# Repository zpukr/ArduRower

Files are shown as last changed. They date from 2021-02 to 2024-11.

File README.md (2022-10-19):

# ArduRower
The project was created on the basis of the ESP32 board (Heltec WiFi Kit 32 - cheap ESP32 board with OLED & LiPo battery interface) for equipping chinese clones of waterrower like Incline, XtremepowerUS, Hunter, Fit-On or DIY rowing machines with a 0.96-inch OLED screen and bluetooth interface. The device have emulates the work of the original WaterRower S4 equipped with a bluetooth comm module. Tested work with the **Coxswain** app, which allows to record and export your workouts to Garmin Connect and/or Strava, work with **Kinomap**, **HOLOFIT** and probably other applications that support the **FiTness Machine Service** protocol better known as **FTMS**. To connect to your rowing machine, you only need to attach two GND and GPIO2 wires to the RPM sensor (you can add 1kΩ resistor or similar on each wire for protection ESP32 board). You can also connect the battery to GPIO33 through a divider of two resistors: 220kΩ resistance connects to "+" of LiPo battery and GPIO33, 100kΩ resistance to GND and GPIO33

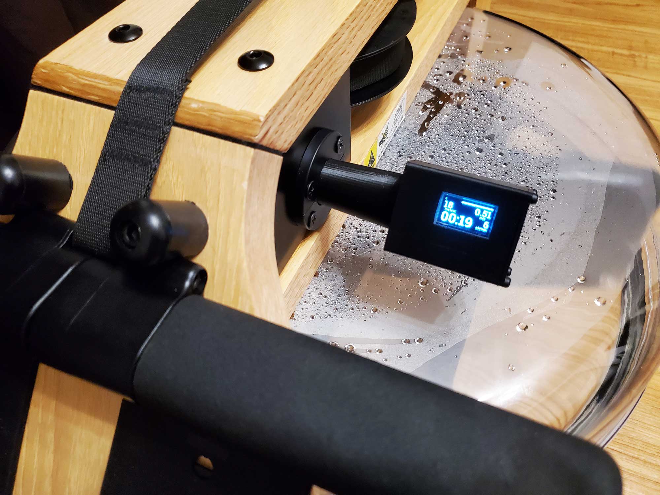
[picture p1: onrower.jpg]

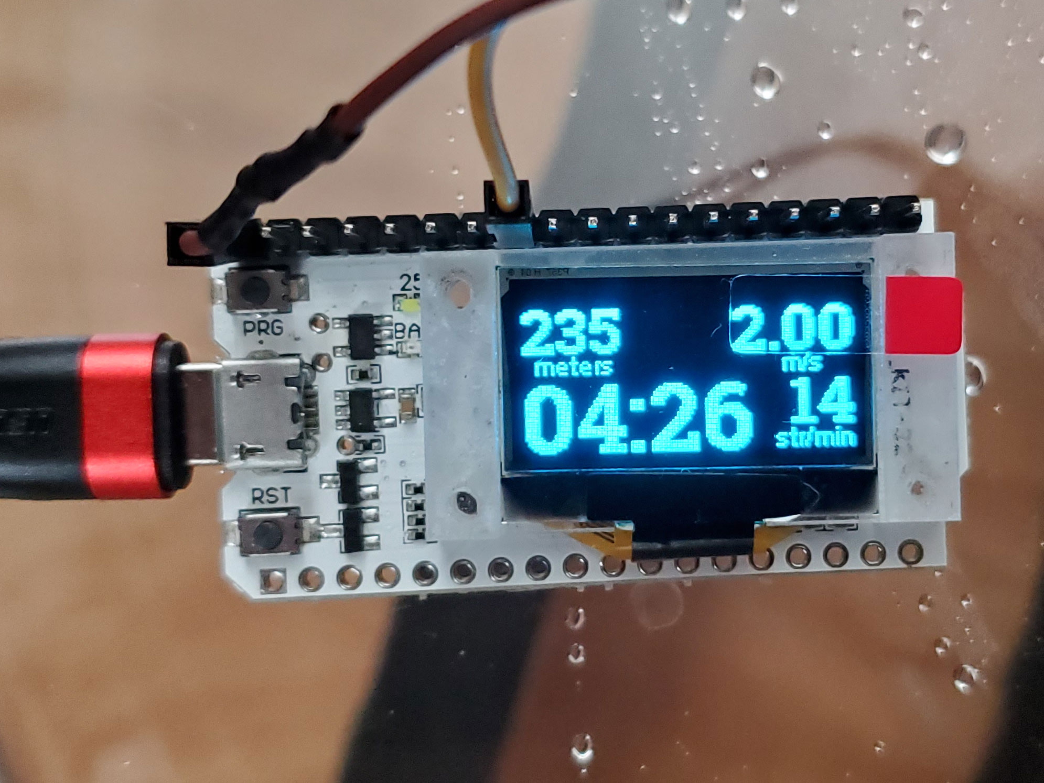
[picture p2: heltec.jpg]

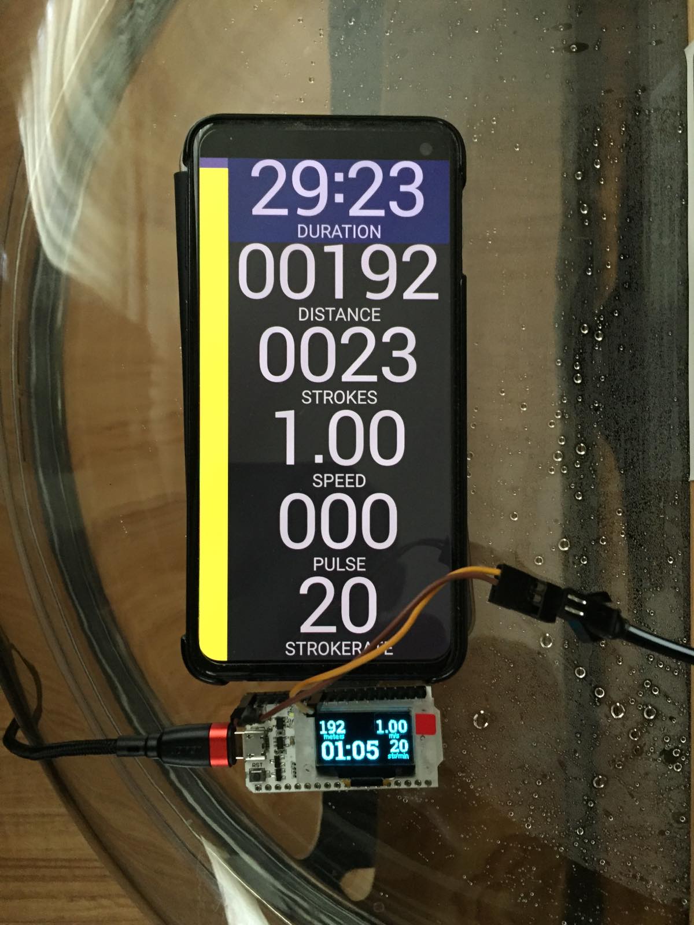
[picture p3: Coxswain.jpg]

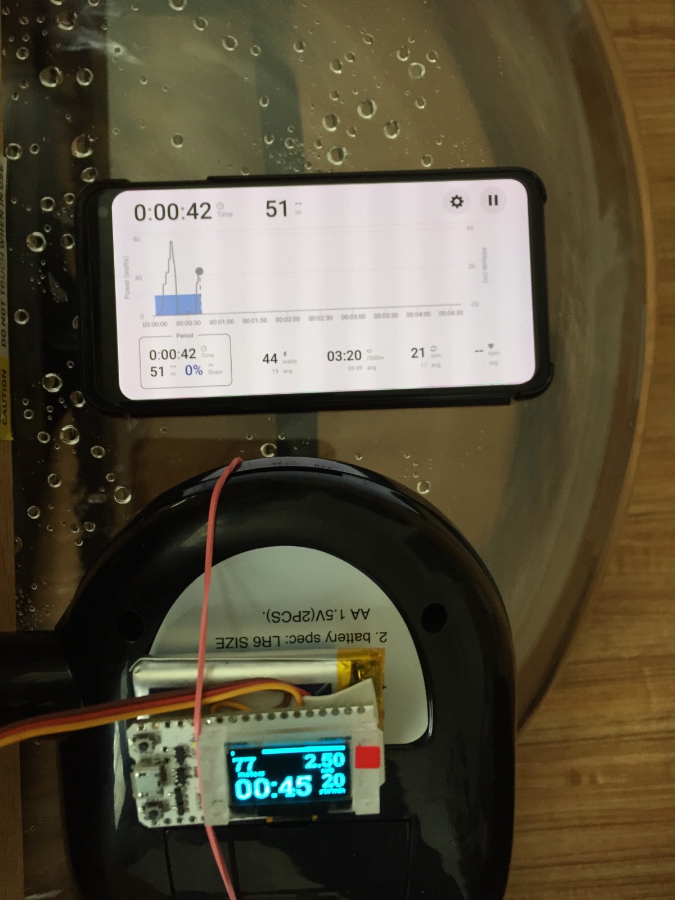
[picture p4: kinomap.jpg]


It is possible to write directly to the Garmin Connect using the Connect IQ DataField **ArduRower-IQ** https://apps.garmin.com/en-US/apps/0e10bae1-9753-4915-b856-040d0cbdd82a 

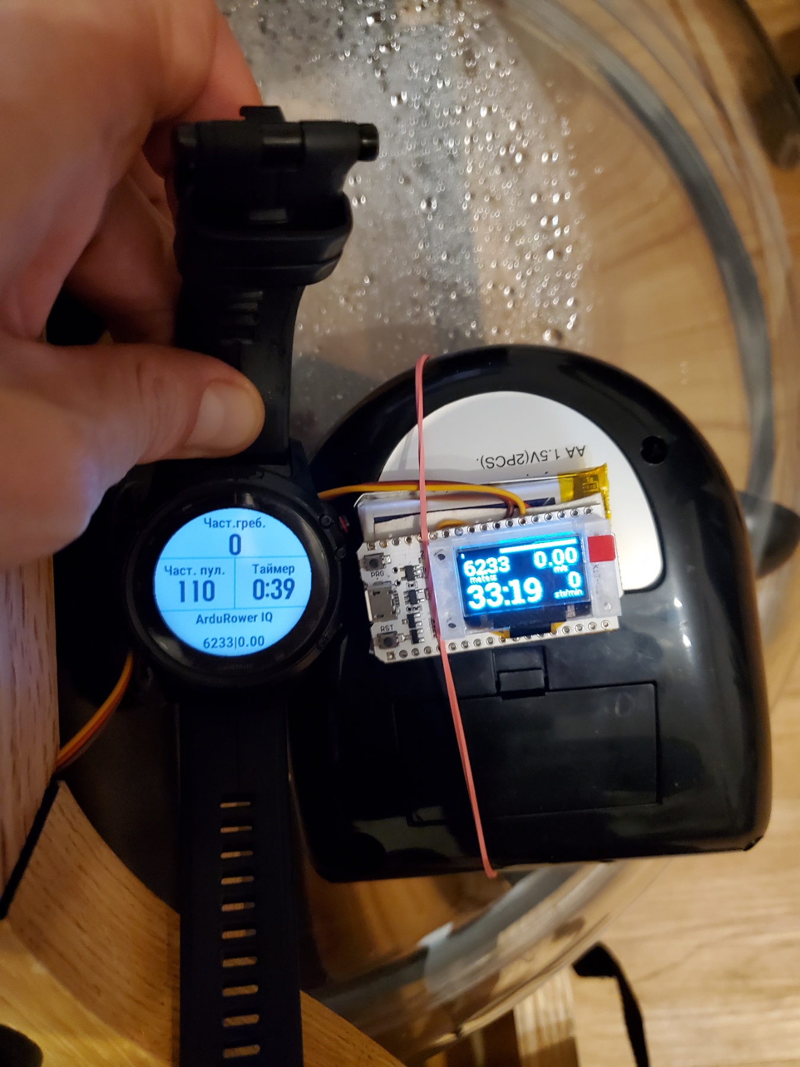
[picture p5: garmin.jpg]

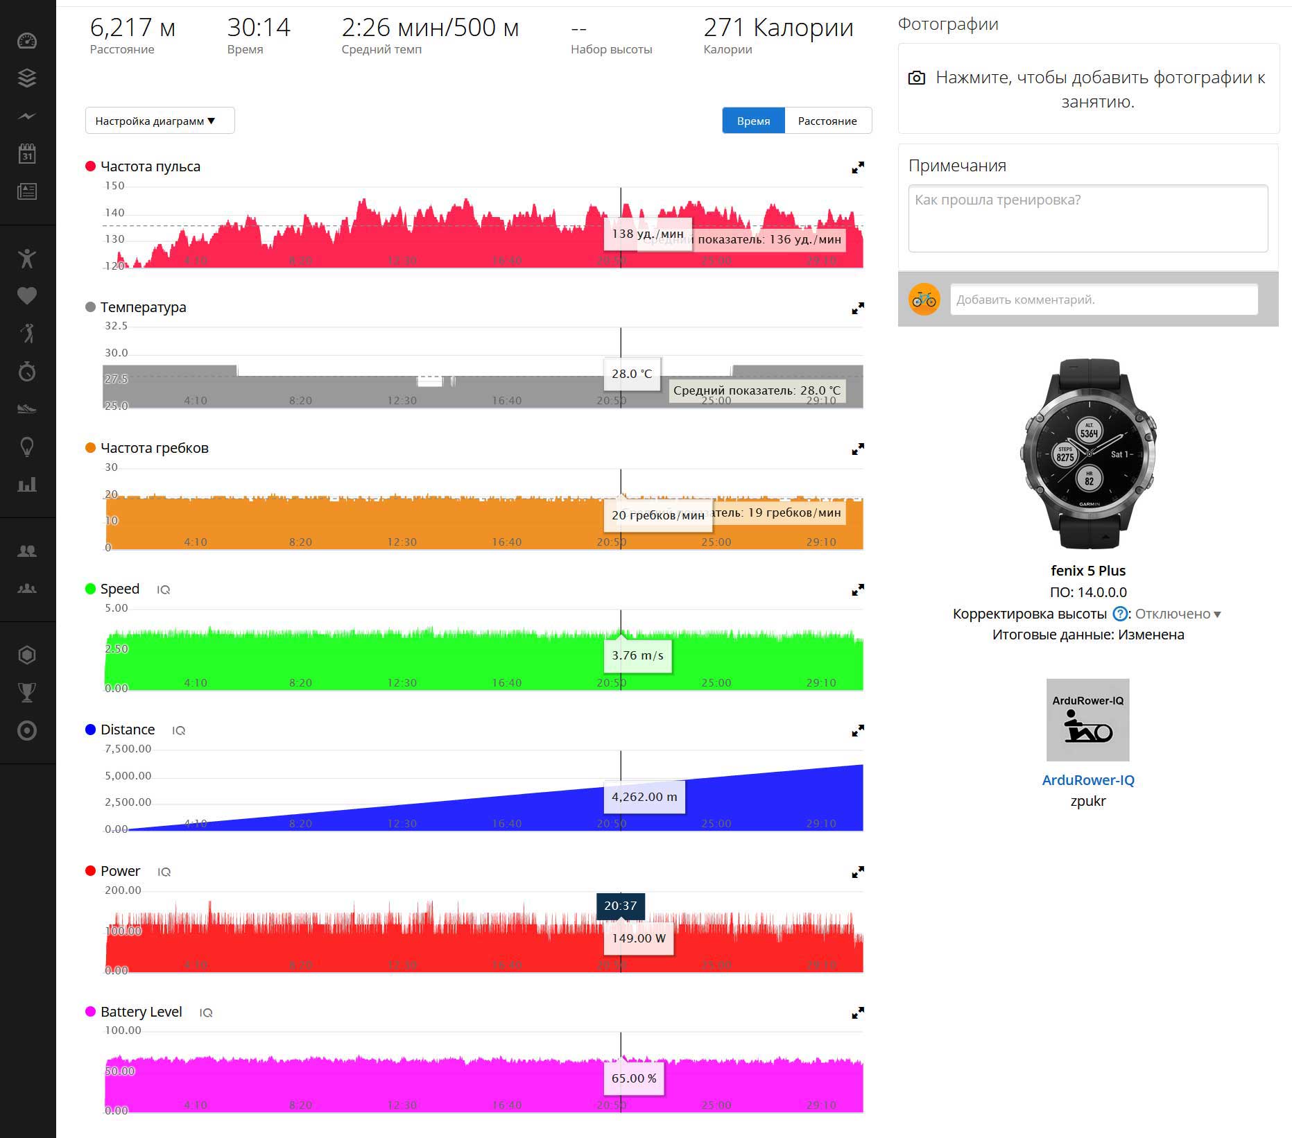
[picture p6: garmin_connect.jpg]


Rower side based on sketch **WaterRino**: https://github.com/adruino-io/waterrino                          
Bluetooth side on sketch **WaterRower S4BL3 Bluetooth BLE for S4**: https://github.com/vibr77/wr_s4bl3_samd

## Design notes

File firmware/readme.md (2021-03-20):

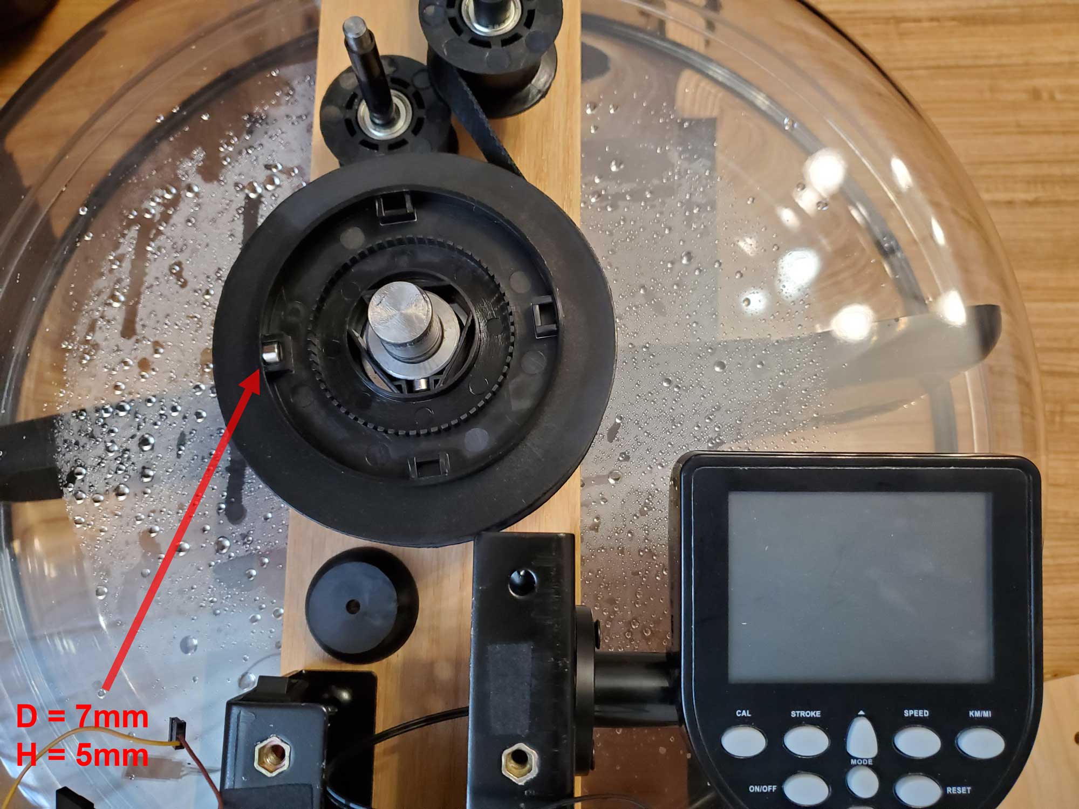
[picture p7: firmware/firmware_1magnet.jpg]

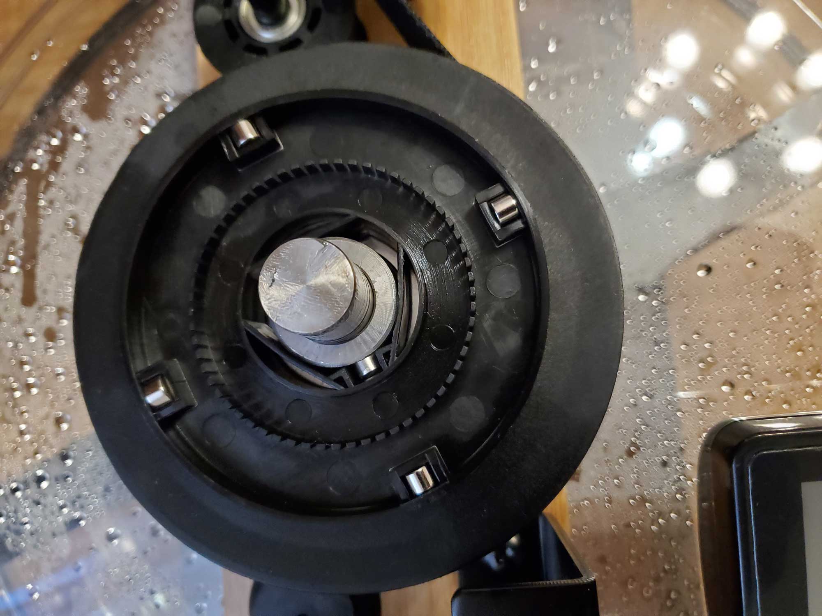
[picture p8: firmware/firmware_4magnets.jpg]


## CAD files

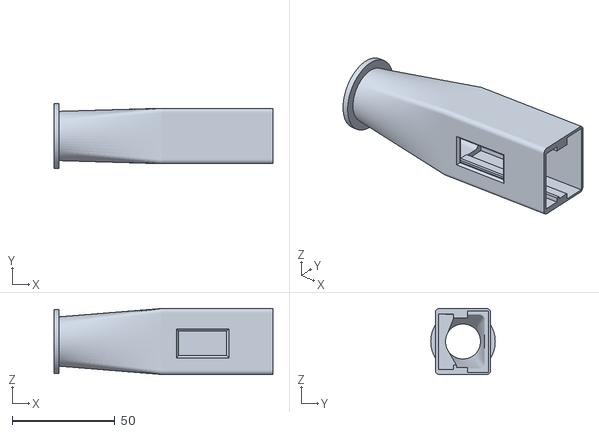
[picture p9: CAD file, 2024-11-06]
3d_print/minimal_case.stl
106.5 x 31.4 x 32.1

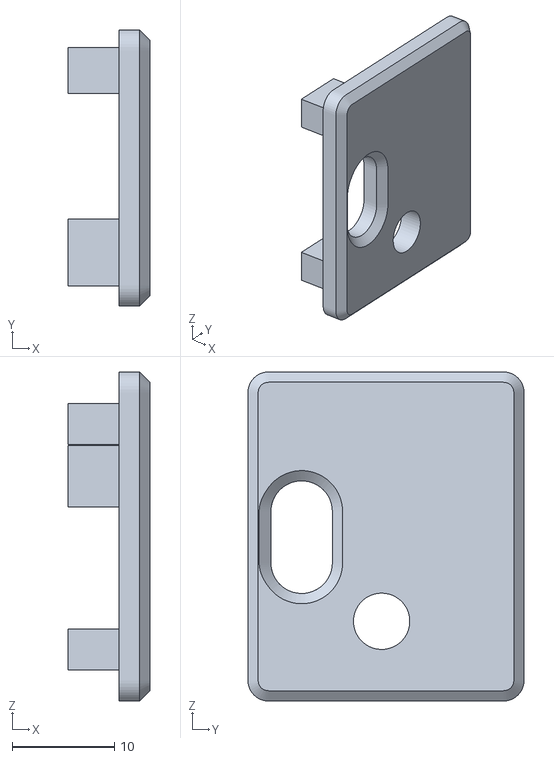
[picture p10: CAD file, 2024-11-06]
3d_print/minimal_cap.stl
8.00 x 27.0 x 32.1

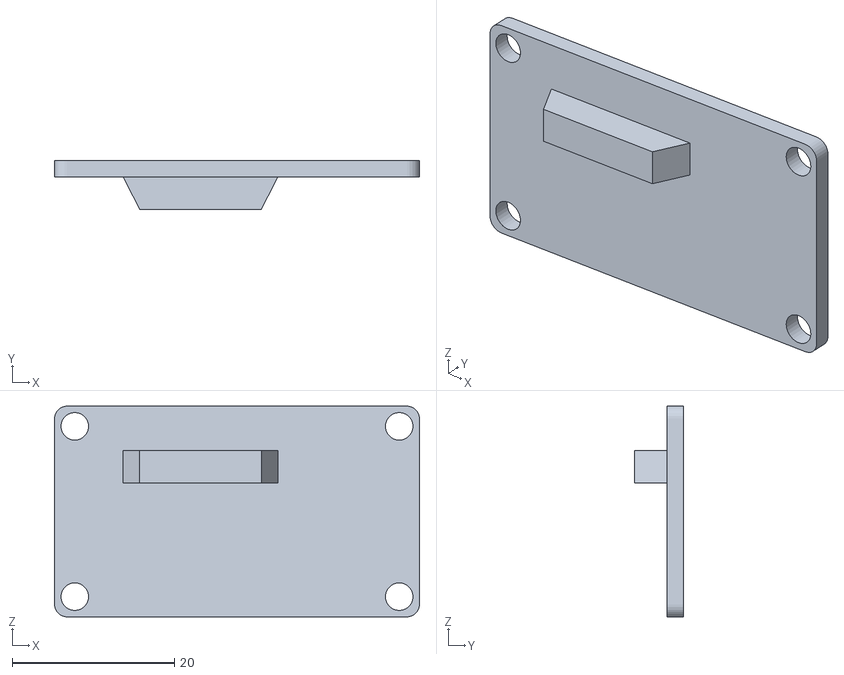
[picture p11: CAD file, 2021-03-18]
3d_print/cap.STL
45.0 x 6.00 x 26.0

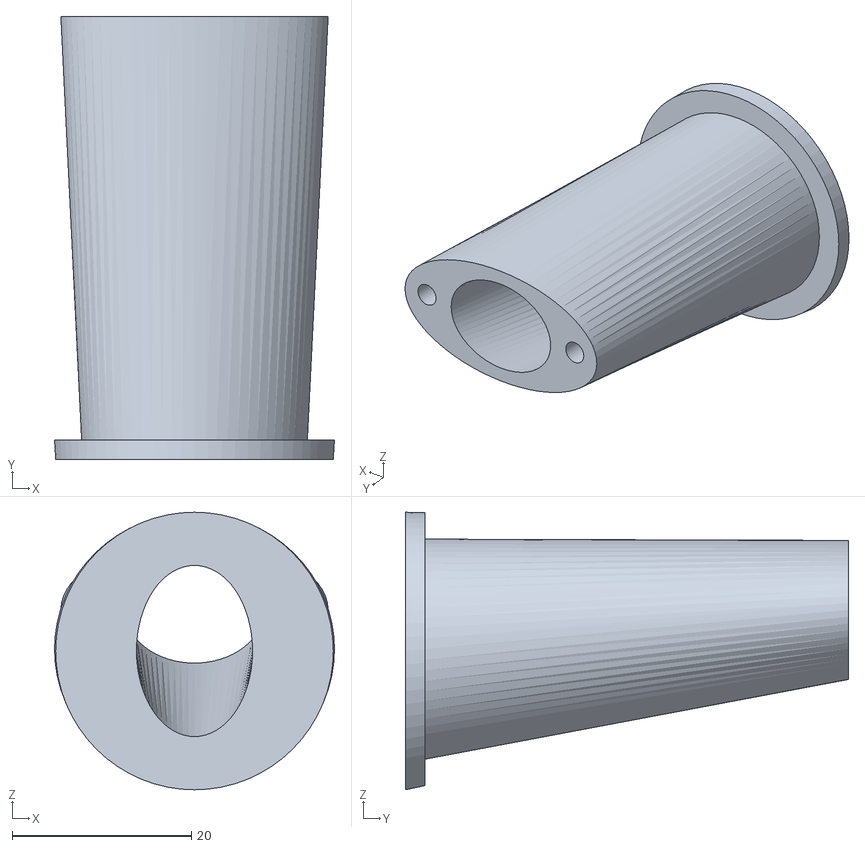
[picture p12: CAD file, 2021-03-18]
3d_print/mount.STL
31.3 x 49.5 x 31.0

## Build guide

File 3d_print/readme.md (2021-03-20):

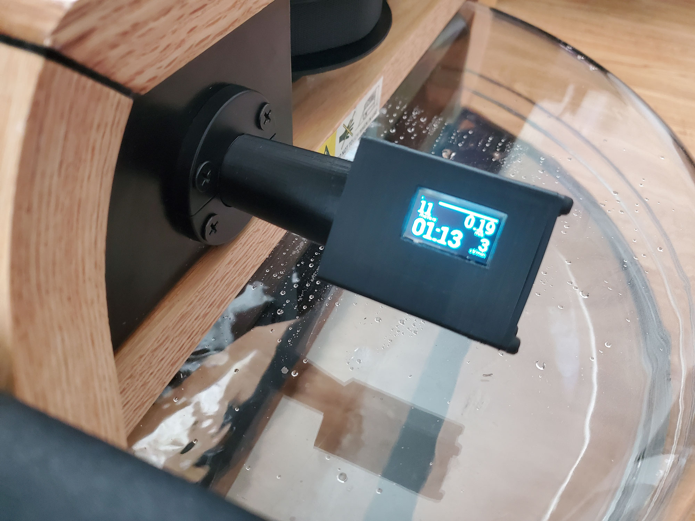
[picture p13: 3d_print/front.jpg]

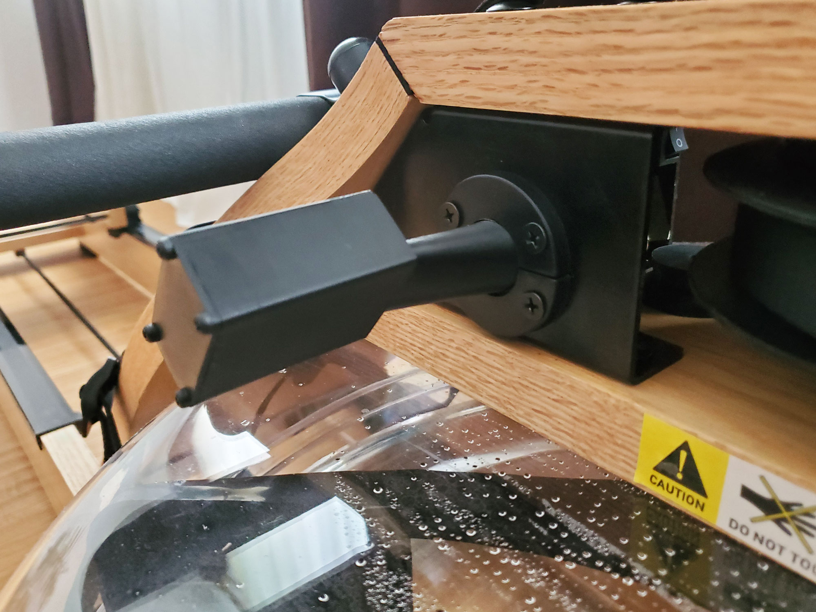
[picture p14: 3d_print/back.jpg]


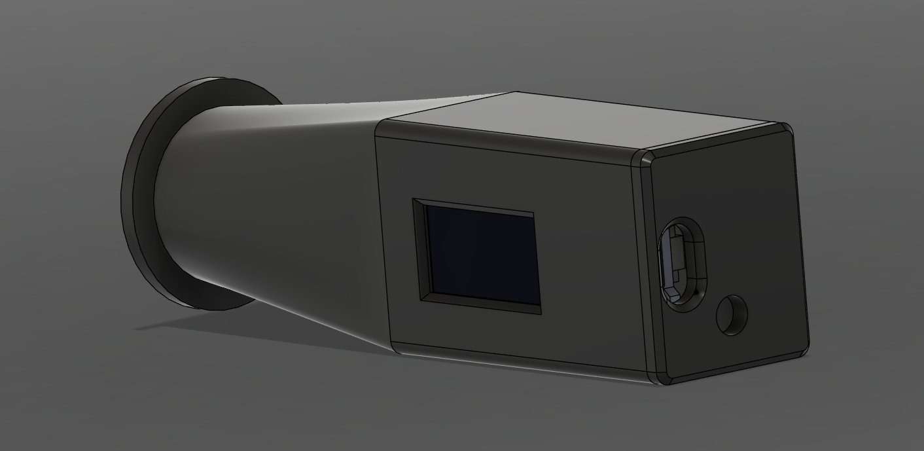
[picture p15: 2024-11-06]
3d_print/minimal_case.png

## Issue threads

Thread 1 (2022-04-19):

Support for Viking Pro V from First Degree Fitness Europe B.V.

de-jens, 2022-04-19:
Hello,

it would be great if the Garmin Watch App cloud collect the data from the Viking Pro V from First Degree Fitness Europe B.V. too.

This Rower work with the Kinomap App.

I recorded some data of this Rower see below.

nRF Connect, 2022-04-19

Rower 8200 (D9:02:1A:XX:XX:XX)

V	19:40:14.982	Connecting to D9:02:1A:XX:XX:XX...
D	19:40:14.982	gatt = device.connectGatt(autoConnect = false, TRANSPORT_LE, preferred PHY = LE 1M)
D	19:40:15.111	[Callback] Connection state changed with status: 0 and new state: CONNECTED (2)
I	19:40:15.111	Connected to D9:02:1A:XX:XX:XX
V	19:40:15.127	Discovering services...
D	19:40:15.127	gatt.discoverServices()
D	19:40:15.141	[Broadcast] Action received: android.bluetooth.device.action.ACL_CONNECTED
I	19:40:15.818	Connection parameters updated (interval: 7.5ms, latency: 0, timeout: 5000ms)
D	19:40:16.133	[Callback] Services discovered with status: 0
I	19:40:16.133	Services discovered
V	19:40:16.146	Generic Access (0x1800)
- Device Name [R W] (0x2A00)
- Appearance [R] (0x2A01)
- Peripheral Preferred Connection Parameters [R] (0x2A04)
- Central Address Resolution [R] (0x2AA6)
Generic Attribute (0x1801)
Unknown Service (0000e0ff-3c17-d293-8e48-14fe2e4da212)
- Unknown Characteristic [N W WNR] (0000ffe1-0000-1000-8000-00805f9b34fb)
   Client Characteristic Configuration (0x2902)
- Unknown Characteristic [N W WNR] (0000ffe2-0000-1000-8000-00805f9b34fb)
   Client Characteristic Configuration (0x2902)
Fitness Machine (0x1826)
- Rower Data [N] (0x2AD1)
   Client Characteristic Configuration (0x2902)
Battery Service (0x180F)
- Battery Level [N R] (0x2A19)
   Client Characteristic Configuration (0x2902)
Device Information (0x180A)
- Software Revision String [R] (0x2A28)
Secure DFU Service (0xFE59)
- Buttonless DFU [I W] (8ec90003-f315-4f60-9fb8-838830daea50)
   Client Characteristic Configuration (0x2902)
D	19:40:16.146	gatt.setCharacteristicNotification(0000ffe1-0000-1000-8000-00805f9b34fb, true)
D	19:40:16.151	gatt.setCharacteristicNotification(0000ffe2-0000-1000-8000-00805f9b34fb, true)
D	19:40:16.152	gatt.setCharacteristicNotification(00002ad1-0000-1000-8000-00805f9b34fb, true)
D	19:40:16.154	gatt.setCharacteristicNotification(00002a19-0000-1000-8000-00805f9b34fb, true)
I	19:40:16.228	Connection parameters updated (interval: 45.0ms, latency: 0, timeout: 5000ms)
I	19:40:21.223	Connection parameters updated (interval: 67.5ms, latency: 0, timeout: 4000ms)
V	19:40:36.616	Reading PHY...
D	19:40:36.616	gatt.readPhy()
I	19:40:36.626	PHY read (TX: LE 1M, RX: LE 1M)
V	19:40:41.115	Enabling services...
V	19:40:41.115	Enabling notifications for 0000ffe1-0000-1000-8000-00805f9b34fb
D	19:40:41.115	gatt.setCharacteristicNotification(0000ffe1-0000-1000-8000-00805f9b34fb, true)
D	19:40:41.117	gatt.writeDescriptor(00002902-0000-1000-8000-00805f9b34fb, value=0x0100)
I	19:40:41.203	Data written to descr. 00002902-0000-1000-8000-00805f9b34fb, value: (0x) 01-00
A	19:40:41.203	"Notifications enabled" sent
V	19:40:41.210	Notifications enabled for 0000ffe1-0000-1000-8000-00805f9b34fb
V	19:40:41.210	Enabling notifications for 0000ffe2-0000-1000-8000-00805f9b34fb
D	19:40:41.217	gatt.setCharacteristicNotification(0000ffe2-0000-1000-8000-00805f9b34fb, true)
D	19:40:41.218	gatt.writeDescriptor(00002902-0000-1000-8000-00805f9b34fb, value=0x0100)
I	19:40:41.339	Data written to descr. 00002902-0000-1000-8000-00805f9b34fb, value: (0x) 01-00
A	19:40:41.339	"Notifications enabled" sent
V	19:40:41.348	Notifications enabled for 0000ffe2-0000-1000-8000-00805f9b34fb
V	19:40:41.363	Enabling notifications for 00002ad1-0000-1000-8000-00805f9b34fb
D	19:40:41.363	gatt.setCharacteristicNotification(00002ad1-0000-1000-8000-00805f9b34fb, true)
D	19:40:41.365	gatt.writeDescriptor(00002902-0000-1000-8000-00805f9b34fb, value=0x0100)
I	19:40:41.473	Data written to descr. 00002902-0000-1000-8000-00805f9b34fb, value: (0x) 01-00
A	19:40:41.473	"Notifications enabled" sent
V	19:40:41.510	Notifications enabled for 00002ad1-0000-1000-8000-00805f9b34fb
V	19:40:41.511	Enabling notifications for 00002a19-0000-1000-8000-00805f9b34fb
D	19:40:41.519	gatt.setCharacteristicNotification(00002a19-0000-1000-8000-00805f9b34fb, true)
D	19:40:41.520	gatt.writeDescriptor(00002902-0000-1000-8000-00805f9b34fb, value=0x0100)
I	19:40:41.608	Data written to descr. 00002902-0000-1000-8000-00805f9b34fb, value: (0x) 01-00
A	19:40:41.609	"Notifications enabled" sent
V	19:40:41.640	Notifications enabled for 00002a19-0000-1000-8000-00805f9b34fb
V	19:40:41.659	Enabling indications for 8ec90003-f315-4f60-9fb8-838830daea50
D	19:40:41.659	gatt.setCharacteristicNotification(8ec90003-f315-4f60-9fb8-838830daea50, true)
D	19:40:41.661	gatt.writeDescriptor(00002902-0000-1000-8000-00805f9b34fb, value=0x0200)
I	19:40:41.743	Data written to descr. 00002902-0000-1000-8000-00805f9b34fb, value: (0x) 02-00
A	19:40:41.743	"Indications enabled" sent
V	19:40:41.750	Indications enabled for 8ec90003-f315-4f60-9fb8-838830daea50
V	19:40:41.761	All services enabled
V	19:40:43.811	Reading all characteristics...
V	19:40:43.811	Reading characteristic 00002a00-0000-1000-8000-00805f9b34fb
D	19:40:43.811	gatt.readCharacteristic(00002a00-0000-1000-8000-00805f9b34fb)
I	19:40:43.904	Read Response received from 00002a00-0000-1000-8000-00805f9b34fb, value: (0x) 52-6F-77-65-72-20-38-32-30-30, "Rower 8200"
A	19:40:43.904	"Rower 8200" received
V	19:40:43.914	Reading characteristic 00002a01-0000-1000-8000-00805f9b34fb
D	19:40:43.914	gatt.readCharacteristic(00002a01-0000-1000-8000-00805f9b34fb)
I	19:40:44.039	Read Response received from 00002a01-0000-1000-8000-00805f9b34fb, value: (0x) 00-00
A	19:40:44.039	"[0] Unknown" received
V	19:40:44.049	Reading characteristic 00002a04-0000-1000-8000-00805f9b34fb
D	19:40:44.049	gatt.readCharacteristic(00002a04-0000-1000-8000-00805f9b34fb)
I	19:40:44.173	Read Response received from 00002a04-0000-1000-8000-00805f9b34fb, value: (0x) 10-00-3C-00-00-00-90-01
A	19:40:44.173	"Connection Interval: 20.00ms - 75.00ms,
Slave Latency: 0,
Supervision Timeout Multiplier: 400" received
V	19:40:44.185	Reading characteristic 00002aa6-0000-1000-8000-00805f9b34fb
D	19:40:44.185	gatt.readCharacteristic(00002aa6-0000-1000-8000-00805f9b34fb)
I	19:40:44.309	Read Response received from 00002aa6-0000-1000-8000-00805f9b34fb, value: (0x) 01
A	19:40:44.309	"Address resolution supported" received
V	19:40:44.319	Reading characteristic 00002a19-0000-1000-8000-00805f9b34fb
D	19:40:44.319	gatt.readCharacteristic(00002a19-0000-1000-8000-00805f9b34fb)
I	19:40:44.445	Read Response received from 00002a19-0000-1000-8000-00805f9b34fb, value: (0x) 64, "d"
A	19:40:44.445	"100%" received
V	19:40:44.454	Reading characteristic 00002a28-0000-1000-8000-00805f9b34fb
D	19:40:44.454	gatt.readCharacteristic(00002a28-0000-1000-8000-00805f9b34fb)
I	19:40:44.581	Read Response received from 00002a28-0000-1000-8000-00805f9b34fb, value: (0x) 32-30-32-31-30-31-31-31-32-32-33-30, "202101112230"
A	19:40:44.581	"202101112230" received
V	19:40:44.591	6 characteristics read
I	19:41:02.471	Notification received from 00002ad1-0000-1000-8000-00805f9b34fb, value: (0x) 05-0A-1D-00-00-00-14-00
A	19:41:02.472	"Total Distance: 29 m
Heart Rate: 0 bpm
Elapsed Time: 20 s" received
I	19:41:02.738	Notification received from 00002ad1-0000-1000-8000-00805f9b34fb, value: (0x) 05-0A-1E-00-00-00-14-00
A	19:41:02.738	"Total Distance: 30 m
Heart Rate: 0 bpm
Elapsed Time: 20 s" received
I	19:41:03.075	Notification received from 00002ad1-0000-1000-8000-00805f9b34fb, value: (0x) 05-0A-1F-00-00-00-14-00
A	19:41:03.076	"Total Distance: 31 m
Heart Rate: 0 bpm
Elapsed Time: 20 s" received
I	19:41:03.414	Notification received from 00002ad1-0000-1000-8000-00805f9b34fb, value: (0x) 05-0A-1F-00-00-00-15-00
A	19:41:03.414	"Total Distance: 31 m
Heart Rate: 0 bpm
Elapsed Time: 21 s" received
I	19:41:03.415	Notification received from 00002ad1-0000-1000-8000-00805f9b34fb, value: (0x) 05-0A-20-00-00-00-15-00
A	19:41:03.415	"Total Distance: 32 m
Heart Rate: 0 bpm
Elapsed Time: 21 s" received
I	19:41:03.886	Notification received from 00002ad1-0000-1000-8000-00805f9b34fb, value: (0x) 05-0A-21-00-00-00-15-00
A	19:41:03.886	"Total Distance: 33 m
Heart Rate: 0 bpm
Elapsed Time: 21 s" received
I	19:41:04.222	Notification received from 00002ad1-0000-1000-8000-00805f9b34fb, value: (0x) 05-0A-22-00-00-00-15-00
A	19:41:04.222	"Total Distance: 34 m
Heart Rate: 0 bpm
Elapsed Time: 21 s" received
I	19:41:04.424	Notification received from 00002ad1-0000-1000-8000-00805f9b34fb, value: (0x) 05-0A-22-00-00-00-16-00
A	19:41:04.424	"Total Distance: 34 m
Heart Rate: 0 bpm
Elapsed Time: 22 s" received
I	19:41:04.829	Notification received from 00002ad1-0000-1000-8000-00805f9b34fb, value: (0x) 05-0A-23-00-00-00-16-00
A	19:41:04.829	"Total Distance: 35 m
Heart Rate: 0 bpm
Elapsed Time: 22 s" received
I	19:41:05.369	Notification received from 00002ad1-0000-1000-8000-00805f9b34fb, value: (0x) 05-0A-24-00-00-00-16-00
A	19:41:05.369	"Total Distance: 36 m
Heart Rate: 0 bpm
Elapsed Time: 22 s" received
I	19:41:05.438	Notification received from 00002ad1-0000-1000-8000-00805f9b34fb, value: (0x) 05-0A-24-00-00-00-17-00
A	19:41:05.438	"Total Distance: 36 m
Heart Rate: 0 bpm
Elapsed Time: 23 s" received
I	19:41:05.775	Notification received from 00002ad1-0000-1000-8000-00805f9b34fb, value: (0x) F8-00-26-03-00-01-01-00-00-14-00-10-00-02-00
A	19:41:05.775	"Stroke Rate: 19.0 stroke/min
Stroke Count: 3
Instantaneous Pace: 257 s
Average Pace: 0 s
Instantaneous Power: 20 W
Average Power: 16 W
Resistance Level: 2" received
I	19:41:05.776	Notification received from 00002ad1-0000-1000-8000-00805f9b34fb, value: (0x) 01-01-01-00-73-01-06
A	19:41:05.776	"Total Energy: 1 kcal
Energy Per Hour: 371 kcal
Energy Per Minute: 6 kcal" received
I	19:41:06.449	Notification received from 00002ad1-0000-1000-8000-00805f9b34fb, value: (0x) 05-0A-26-00-00-00-18-00
A	19:41:06.449	"Total Distance: 38 m
Heart Rate: 0 bpm
Elapsed Time: 24 s" received
I	19:41:07.462	Notification received from 00002ad1-0000-1000-8000-00805f9b34fb, value: (0x) 05-0A-29-00-00-00-19-00
A	19:41:07.462	"Total Distance: 41 m
Heart Rate: 0 bpm
Elapsed Time: 25 s" received
I	19:41:08.480	Notification received from 00002ad1-0000-1000-8000-00805f9b34fb, value: (0x) 05-0A-2A-00-00-00-1A-00
A	19:41:08.480	"Total Distance: 42 m
Heart Rate: 0 bpm
Elapsed Time: 26 s" received
I	19:41:09.498	Notification received from 00002ad1-0000-1000-8000-00805f9b34fb, value: (0x) 05-0A-2C-00-00-00-1B-00
A	19:41:09.498	"Total Distance: 44 m
Heart Rate: 0 bpm
Elapsed Time: 27 s" received
I	19:41:09.623	Notification received from 00002ad1-0000-1000-8000-00805f9b34fb, value: (0x) F8-00-1F-04-00-F2-00-00-00-18-00-11-00-02-00
A	19:41:09.623	"Stroke Rate: 15.5 stroke/min
Stroke Count: 4
Instantaneous Pace: 242 s
Average Pace: 0 s
Instantaneous Power: 24 W
Average Power: 17 W
Resistance Level: 2" received
I	19:41:09.623	Notification received from 00002ad1-0000-1000-8000-00805f9b34fb, value: (0x) 01-01-02-00-81-01-06
A	19:41:09.623	"Total Energy: 2 kcal
Energy Per Hour: 385 kcal
Energy Per Minute: 6 kcal" received
I	19:41:10.517	Notification received from 00002ad1-0000-1000-8000-00805f9b34fb, value: (0x) 05-0A-2E-00-00-00-1C-00
A	19:41:10.517	"Total Distance: 46 m
Heart Rate: 0 bpm
Elapsed Time: 28 s" received
I	19:41:11.516	Notification received from 00002ad1-0000-1000-8000-00805f9b34fb, value: (0x) 05-0A-31-00-00-00-1D-00
A	19:41:11.516	"Total Distance: 49 m
Heart Rate: 0 bpm
Elapsed Time: 29 s" received
I	19:41:12.526	Notification received from 00002ad1-0000-1000-8000-00805f9b34fb, value: (0x) 05-0A-33-00-00-00-1E-00
A	19:41:12.526	"Total Distance: 51 m
Heart Rate: 0 bpm
Elapsed Time: 30 s" received
I	19:41:13.133	Notification received from 00002ad1-0000-1000-8000-00805f9b34fb, value: (0x) F8-00-22-05-00-EB-00-00-00-1B-00-12-00-02-00
A	19:41:13.133	"Stroke Rate: 17.0 stroke/min
Stroke Count: 5
Instantaneous Pace: 235 s
Average Pace: 0 s
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

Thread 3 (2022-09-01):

contact to the author

damndemento, 2022-09-01:
Hi... this is not an issue at all ;)

but I would like to contact @zpukr to ask a questions regarding the ArduRower project.

Is it possible to run this on an ESP32 without display, I'm asking because I'm planning to add BLE support to my "Vendomnia Rower" but want to use the included rower-display in parallel... and just to be clear, you used platformio to flash the ESP32??

would be nice to get a reply from you on this way, sorry but I couldn't find another way to contact you....

cheers,

Dan

zpukr, 2022-09-01:
Yes, you can use the esp32 without a connected display, no modifications to the source code are required. But, of course, you can also clean up the code from unnecessary instructions. The answer to the second question - the project was compiled into PlatformIO, and yes you can also use the Arduino IDE, but I recommend platformIO

zpukr, 2022-09-01:
Forgot. Yes, you can use ready-made firmware in the form of a .bin file, although the version there is somewhat outdated, but mainly the changes concerned the optimization of the display image.

damndemento, 2022-09-01:
thanks a lot for your quick reply - I'll have a look at the code, maybe I can get rid of the unused code ;)
I use platformio via VSCode so this should work! Nice project thanks again...

damndemento, 2022-09-06:
Hi @zpukr ;)

sorry to disturb you again, but I have one last question regarding your code.

You specified pin 2 for sensor data... is this a "board pin" or "gpio pin" number? I'm asking 'cause I'm actually using a "D1 mini ESP32" and have to find the right pin on the board. I managed to compile your code for my board and uploaded it. So far It seems to be working - it's available via coxswain... right now I'm looking for some 1k resistors ;)

hope you can help one last time...

zpukr, 2022-09-06:
you can change the pin number to any valid for esp32. I have here this GPIO2 and not the pin of the board. Arduino does not know all the pins of hundreds of types of boards, so the GPIO numbering is mainly used as universal for different tipes of boards.

> const int ROWERINPUT = 2; // the input pin where the waterrower sensor is connected

damndemento, 2022-09-07:
Hi zpukr,

ok this makes things clearer - I remembered one of my raspi projects in python where you can define which numbering is used for the pins. I asked because I didn't find this declaration in your src.ino and to avoid errors I thought it's better to ask...
Good to know that arduino-code always uses gpio pin numbers ;)

thanks a ton!

cheers,

Dan

OhNoItSJoe, 2023-01-08:
Hi @zpukr, also using this thread for a few questions.
Thanks for this great project already!

I ordered myself a rowing machine the same type you have, and already want to order the Heltec board (v3) and some additional magnets.
- How do you charge the battery?
- Which battery type are you using?
- How does the ESP know when training starts? aka how does it get turned on?

zpukr, 2023-01-08:
>How do you charge the battery?
The Heltec board has a built-in charge controller. Just connect the microUSB cable and the battery is charged
>Which battery type are you using?
Any lithium polymer battery of the right size for you, the minimum capacity is 500 mAh, this should be enough for 5 hours of training. You can put a larger battery, 1000mAh or even 2000mAh, but this does not make much sense if you are not going to row for a day without stopping. The problem may arise with searching the battery connector on the Heltech board, it is not quite standard, although not very rare
>How does the ESP know when training starts? aka how does it get turned on?
I installed a simple switch in the positive, red wire of the battery. I clicked the switch, the esp32 worked, the device went into ready mode. As soon as you start rowing, the workout will automatically start. You can do without a battery and switch at all, just power the device using a microUSB cable, this is not very convenient, but for the first time it’s definitely enough

OhNoItSJoe, 2023-01-08:
Oh, the switch is a good idea. Did you also integrate that in a 3D printed case?
And do you think that this ESP32 will work?
https://www.amazon.de/-/en/WiFi-Development-Kit-32-Consumption/dp/B099ZN8BFC

zpukr, 2023-01-08:
*Did you also integrate that in a 3D printed case?
Yes, of course, I think you have seen my photos of the case. The STL model is posted in the 3d_print folder. I don't remember exactly the capacity and size of my battery (maybe 700mah?) and I can't look at it as my house has been taken over by Russian troops and I haven't seen my house or rower in over 10 months. Today I'm homeless which is a minus, but still alive is a plus
*And do you think that this ESP32 will work?
I can't be 100% sure because I used a different revision of the board and you can see it in the photo. But with a 99% chance everything will work fine

OhNoItSJoe, 2023-01-08:
Oh shit, sucks to hear that. Good that you're alive tho!
Got a donation site?

zpukr, 2023-01-08:
*Got a donation site?
thank you very much, but I don't need donations, have food and lodging. I just want to get home as soon as possible, but any money can't buy that. Let's not talk about sad things, if you have any questions about esp32, ask, I will try to answer when possible

mjcuadrado, 2023-04-04:
hi zpukr i am trying to get the project working with an original Waterrower.  In the photos I see that you have one.  I can't get exercise to be detected.  I understand that the red wire should go to pin 2 and the blue and green wires should join and go to GND.  Am I correct?

Thanks

zpukr, 2023-04-04:
Wrong. I don't have the original Water Rover. This is a Chinese clone of Water Rover. I don't know what wires you're talking about, but if it's the wires that come from the rowing machine, you can find the wires you need with a regular multimeter. Switch the multimeter to the resistance measurement mode and start rowing on the rowing machine. On the wires you need, the resistance should periodically change from 0 to infinity, the faster you row, the more often these values will change places.

mjcuadrado, 2023-04-04:
Hello, thank you very much for answering so quickly.  Now I understand why after different tests it didn't work!  I think during one of these tests my optical sensor died because it is not detected by the original monitor either.  I have ordered several replacements and will try next week when I replace it.

Another thing, for the project to work with the Wifi Kit V3 board you have to modify the instance to the lcd.  I think it could be conditioned depending on the type of plate.  When I advanced a little more I investigate it

zpukr, 2023-04-04:
I apologize for the misinformation! I searched on the Internet, WaterRover really has an optical sensor (3 wires) and not a magnetic one (two wires). The optical sensor is a little more complicated, it needs a third wire for normal operation - power. You can detect power on a wire by putting the multimeter in voltage measurement mode. Usually the red wire is the positive power wire, the blue wire is the negative (ground), and the green wire is the signal that needs to be connected to the GPIO2. But first you should test it with a multimeter, this is just my guess!
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
zpukr, 2025-02-05:
> Connecting to the rower is sometimes tricky, but when it is connected:

Finally the problem is becoming clearer! All your troubles are due to the fact that for some reason the data field does not receive the distance from the rowing machine, so if the distance is 0, the final table is empty. You also see this zero in front of the ‘|’ symbol on the watch screen. Battery level can be ignored, it is almost useless metric. The data field receives the distance from the Fitness Machine service (0x1826) > Rower Data characteristic (0x2AD1), according to the FTMS protocol. With nrf connect, you can check for yourself whether the rowing machine transmits distance travelled data or not

Zilibobba, 2025-03-12:
> привет zpukr, я пытаюсь заставить проект работать с оригинальным Waterrower. На фотографиях я вижу, что у вас есть один. Я не могу обнаружить упражнение. Я понимаю, что красный провод должен идти к контакту 2, а синий и зеленый провода должны соединиться и пойти к GND. Я прав?
>
> Спасибо

Hi, did you manage to get the ArduRower project to work with the original Waterrower?

zpukr, 2025-03-12:
> Hi, did you manage to get the ArduRower project to work with the original Waterrower? I have never worked with Arduino or programmed before, it's new to me. I would be very grateful for any help.

Of course I don't have the original waterrover, in fact I haven't owned any rowing machine since the war started Feb 24, 2022. But actually my project should work with any rowing machine that is equipped with a sensor that sends electrical impulses when the flywheel rotates, any not just the waterwheel. As written in the description you need to connect to this sensor on the machine (magnetic, optical, mechanical, electronic - any) just two wires GND for the ground and GPIO2 to which the voltage from the sensor will be supplied.

Zilibobba, 2025-03-12:
> > Hi, did you manage to get the ArduRower project to work with the original Waterrower? I have never worked with Arduino or programmed before, it's new to me. I would be very grateful for any help.
>
> Of course I don't have the original waterrover, in fact I haven't owned any rowing machine since the war started Feb 24, 2022. But actually my project should work with any rowing machine that is equipped with a sensor that sends electrical impulses when the flywheel rotates, any not just the waterwheel. As written in the description you need to connect to this sensor on the machine (magnetic, optical, mechanical, electronic - any) just two wires GND for the ground and GPIO2 to which the voltage from the sensor will be supplied.

Hi. I admire your project, but apparently it is the only project that can make the original Waterrower rowing machine work. Above, user mjcuadrado solved the problem with connecting Waterrower. But I have not yet figured out how to write to him personally. That's why I bothered you. Sorry. I'll try to figure it all out.

zpukr, 2025-03-12:
> That's why I bothered you. Sorry. I'll try to figure it all out.

It's no problem for me to give you advice. As I would have done when faced with an unknown rowing machine, I would have taken a multimeter and slowly rotating the flywheel would look for two wires on which voltage appears and disappears when rotating the flywheel, i.e. there are pulses.  The voltage should not be higher than 3.3V, if more, you still need a simple voltage divider on 2 resistors.

Zilibobba, 2025-03-12:
@mjcuadrado Hello. How can I contact you personally?

Zilibobba, 2025-03-13:
I don't understand, the firmware was installed, there were no errors. When the chip is connected via type-c, a yellow diode is lit on the board, the screen naturally shows nothing. I connect the battery, the diode does not light up, I connect the type-c wire with the battery, the diode starts to shine three times brighter. I haven't tried to connect it to the rowing yet. But strange behavior.

zpukr, 2025-03-13:
> I don't understand, the firmware was installed

I can't say why you can't see anything on the screen, maybe the firmware didn't load properly, maybe something changed in the Heltec board device, that's how I used an earlier revision of the board. However, once the board is powered on, it should automatically create a bluetooth device named “WR S4BL3” which you can detect with your phone. If you don't find such a device, then the firmware didn't load and/or the device doesn't work.
Also I don't have a simple answer what to do, I suggest you upload the firmware via ArduinoIDE or PlatformIO which have normal debugging. Unfortunately MINIMAL knowledge to use Arduino
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

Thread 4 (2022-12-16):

Garmin Instinct 2

Hascii26, 2022-12-16:
Hi @zpukr,

is it possible to make the Garmin App compatible to the Instinct 2?

Thank you

zpukr, 2022-12-16:
done
1.2.5 Add support of Instinct 2

Hascii26, 2022-12-19:
Thank you very much, but I can't find it in the IQ store over Garmin Connect. The list of compatible devices says, that the Instinct is not compatible. I'm from Germany, don't know if that's the problem.

zpukr, 2022-12-19:
hm... App v1.2.5 has been 'pending' for 3 days now, when it usually took minutes. I will try ask Garmin Connect support to solve this problem

Closed 2022-12-16.

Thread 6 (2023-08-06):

connection clarification question / lap measurements S4 water rower

john-2000, 2023-08-06:
First a very, very big thank you for this program! Secondly I am not sure if this is the right way to contact you and if I should have sent an email via the Garmin IQ store apologies. Hopefully the community can help me with my questions

My question relates to the distance measurement - I use the Garmin IQ app.

To confirm to get the connection with the S4 on the water rower to the Garmin Watch - I think its should work by just starting the indoor rowing app with the ArduRower-IQ fields active. Do I need to do anything else? If the S4 is connected to my phone does this interfere with the connection to my Garmin Watch?

Do you know if it is possible to get autolaps working based on distance, it would be brilliant if an automatic lap were recorded in the Garmin history after every XXXm

a very very big thank you for your work!

zpukr, 2023-08-06:
_starting the indoor rowing app with the ArduRower-IQ fields active. Do I need to do anything else?_
nope
_If the S4 is connected to my phone does this interfere with the connection to my Garmin Watch?_
Bluetooth only supports one active connection, so you'll have to choose. As an option to solve the problem, you can also connect ArduRower on esp32 in parallel to the rotation sensor of the rowing machine, even without a screen, so that it works as a bluetooth server just for data transfer.
_autolaps working based on distance_
Garmin does not allow third-party applications to write to native fields like distance, so you will not be able to use the distance provided by ardurower-iq as an automatic lap, unfortunately. Use the time, I have no other options

Closed 2023-08-06.

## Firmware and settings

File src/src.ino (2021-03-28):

#include <BLEDevice.h>
#include <BLEServer.h>
#include <BLEUtils.h>
#include <BLEAdvertising.h>
#include <BLE2902.h>
#include "RunningAverage.h" // https://github.com/RobTillaart/Arduino/tree/master/libraries/RunningAverage

//#include "esp_bt_main.h"
//#include "esp_gap_bt_api.h"

#include "SSD1306.h"
#include "font.h" //// Created by http://oleddisplay.squix.ch/

#define btnRIGHT  0
#define btnUP     1
#define btnDOWN   2
#define btnLEFT   3
#define btnSELECT 4
#define btnNONE   5

// Oled Display
#define SDA    4
#define SCL   15
#define RST_LED   16 //RST must be set by software
//SSD1306  display(0x3c, SDA, SCL, RST_LED);
SSD1306  display(0x3c, 4, 15, GEOMETRY_128_64);                // ADDRESS, SDA, SCL, GEOMETRY_128_32 (or 128_64)

// Global Define 
#define _VERSION          0.05
#define BLE_SERVICE_NAME "WR S4BL3"           // name of the Bluetooth Service 

#define BATPIN 33                            
#define MinADC 1095 
#define MaxADC 1437

#define SerialDebug Serial                   // Usb is used by S4, additionnal port on SAMD21
      
#define FitnessMachineService       0x1826
#define FitnessMachineControlPoint  0x2AD9    // Beta Implementation
#define FitnessMachineFeature       0x2ACC    // CX Not implemented yet
#define FitnessMachineStatus        0x2ADA    // Beta Implementation
#define FitnessMachineRowerData     0x2AD1    // CX Main cx implemented
#define DEVICE_INFORMATION          0x180A

#define batteryService              0x180F    // Additionnal battery service
#define batteryLevel                0x2A19    // Additionnal cx to battery service

BLEServer *pServer = NULL;
BLECharacteristic * pCtrCharacteristic;
BLECharacteristic * pDtCharacteristic;
BLECharacteristic * pFmfCharacteristic;
BLECharacteristic * pStCharacteristic;
BLECharacteristic * pBatCharacteristic;
BLEAdvertising *pAdvertising;

BLECharacteristic * pCharacteristic24;
BLECharacteristic * pCharacteristic25;
BLECharacteristic * pCharacteristic26;
BLECharacteristic * pCharacteristic27;
BLECharacteristic * pCharacteristic28;
BLECharacteristic * pCharacteristic29;

bool deviceConnected = false;
bool oldDeviceConnected = false;
//uint32_t value = 0;
//uint8_t txValue = 0;

// Service
int32_t fitnessMachineServiceId;
int32_t batteryServiceId;

uint16_t  rowerDataFlagsP1=0b0000011111110;
uint16_t  rowerDataFlagsP2=0b1111100000001;

  //P1
  // 0000000000001 - 1   - 0x001 - More Data 0 <!> WARNINNG <!> This Bit is working the opposite way, 0 means field is present, 1 means not present
  // 0000000000010 - 2   - 0x002 - Average Stroke present
  // 0000000000100 - 4   - 0x004 - Total Distance Present
  // 0000000001000 - 8   - 0x008 - Instantaneous Pace present
  // 0000000010000 - 16  - 0x010 - Average Pace Present
  // 0000000100000 - 32  - 0x020 - Instantaneous Power present
  // 0000001000000 - 64  - 0x040 - Average Power present
  // 0000010000000 - 128 - 0x080 - Resistance Level present
  //P2
  // 0000100000000 - 256 - 0x080 - Expended Energy present
  // 0001000000000 - 512 - 0x080 - Heart Rate present
  // 0010000000000 - 1024- 0x080 - Metabolic Equivalent present
  // 0100000000000 - 2048- 0x080 - Elapsed Time present
  // 1000000000000 - 4096- 0x080 - Remaining Time present

  //  C1  Stroke Rate             uint8     Position    2 (After the Flag 2bytes)
  //  C1  Stroke Count            uint16    Position    3 
  //  C2  Average Stroke Rate     uint8     Position    5
  //  C3  Total Distance          uint24    Position    6
  //  C4  Instantaneous Pace      uint16    Position    9
  //  C5  Average Pace            uint16    Position    11
  //  C6  Instantaneous Power     sint16    Position    13
  //  C7  Average Power           sint16    Position    15
  //  C8  Resistance Level        sint16    Position    17
  //  C9  Total Energy            uint16    Position    19
  //  C9  Energy Per Hour         uint16    Position    21
  //  C9  Energy Per Minute       uint8     Position    23
  //  C10 Heart Rate              uint8     Position    24
  //  C11 Metabolic Equivalent    uint8     Position    25
  //  C12 Elapsed Time            uint16    Position    26
  //  C13 Remaining Time          uint16    Position    28

  // fitnessMachineControlPointId
  // OPCODE     DESCRIPTION                                             PARAMETERS
  // 0x01       Reset                                                   N/A
  // 0x02       Fitness Machine Stopped or Paused by the User
  // 0x03       Fitness Machine Stopped by Safety Key                   N/A
  // 0x04       Fitness Machine Started or Resumed by the User          N/A
  // 0x05       Target Speed Changed
  // 0x06       Target Incline Changed
  // 0x07       Target Resistance Level Changed
  // 0x08       Target Power Changed
  // 0x09       Target Heart Rate Changed
  // 0x0B       Targeted Number of Steps Changed                        New Targeted Number of Steps Value (UINT16, in Steps with a resolution of 1)
  // 0x0C       Targeted Number of Strides Changed                      New Targeted Number of Strides (UINT16, in Stride with a resolution of 1)
  // 0x0D       Targeted Distance Changed                               New Targeted Distance (UINT24, in Meters with a resolution of 1)
  // 0x0E       Targeted Training Time Changed                          New Targeted Training Time (UINT16, in Seconds with a resolution of 1)


struct rowerDataKpi{
  int bpm; // Start of Part 1
  int strokeCount;
  //int tmpstrokeRate;
  int strokeRate;
  int averageStokeRate;
  int totalDistance;
  int instantaneousPace;
  int tmpinstantaneousPace;
  int averagePace;
  int instantaneousPower;
  int averagePower;
  int resistanceLevel;
  int totalEnergy; // Start of Part 2
  int energyPerHour;
  int energyPerMinute;
  int heartRate;
  int metabolicEquivalent;
  int elapsedTime;
  int elapsedTimeSec;
  int elapsedTimeMin;
  int elapsedTimeHour;
  int remainingTime;
};

struct rowerDataKpi rdKpi;

bool bleInitFlag=false;
bool bleConnectionStatus=false;

unsigned long currentTime=0;
unsigned long previousTime=0;
unsigned long battPreviousTime=0;

/*-----------------SETUP--PINS-----------------------------*/
const int ROWERINPUT = 2; // the input pin where the waterrower sensor is connected
const int BUTTONSPIN = 0;

/*-----------------CONSTANTS-------------------------------*/
//const float Ratio = 4.8; // from old script 4.8; meters per rpm = circumference of rotor (D=34cm) -> 1,068m -> Ratio = 0.936 ; WaterRower 7,3 m/St. -> Ratio: 3.156
//const float Ratio = 0.79; //one magnet
const float Ratio = 3.156;

RunningAverage stm_RA(21); // size of array for strokes/min
RunningAverage mps_RA(7); // size of array for meters/second -> emulates momentum of boat
RunningAverage battery_RA(40);

/*-----------------VARIABLES-----------------------------*/
long start;
float rounds;
volatile unsigned long click_time = 0;
volatile unsigned long last_click_time = 0;
volatile unsigned long old_split = 0;
volatile unsigned long split_time = 0;
volatile unsigned long start_split;
long debouncing_time = 15; //Debouncing Time in Milliseconds
volatile unsigned long last_micros;
volatile int clicks = 0;
volatile int clicks_old = 0;
volatile float data_output = 0;
volatile long rpm = 0;
volatile long old_rpm = 0;
volatile long stm = 0;
volatile int old_strokes = 0;
volatile float spm = 0;
int old_spm = 0;
volatile long stmra = 0;
int accel = 0;
int puffer = 0;
volatile float Ms = 0;
volatile int meters = 0;
volatile int meters_old = 0;
//volatile int trigger = 0;
unsigned long timer1 = 0;
unsigned long timer2 = 0;
int stage = 0; // sets case for what parameter to be displayed
int rotation = 0;
int strokes = 0;
int trend = 0;
int resetTimer = 0;


class MyServerCallbacks: public BLEServerCallbacks {
    void onConnect(BLEServer* pServer) {
      deviceConnected = true;
      SerialDebug.println("CONNECTED");
      resetTimer = 0;
    };
    void onDisconnect(BLEServer* pServer) {
      deviceConnected = false;
      SerialDebug.println("DISCONNECTED");
      
    }
};

class MyCallbacks: public BLECharacteristicCallbacks {
    void onWrite(BLECharacteristic *pCharacteristic) {
      std::string rxValue = pCharacteristic->getValue();
      if (rxValue.length() > 0) {
        SerialDebug.println("*********");
        SerialDebug.print("Received Value: ");
        if (rxValue.empty())
          SerialDebug.print("-Null-");
        else {
          for (int i = 0; i < rxValue.length(); i++) {
            char chr = rxValue[i];
            SerialDebug.print(chr + "Int:" + (int)chr);
          }
        }  
          SerialDebug.println();
        SerialDebug.println("*********");
      }
    }
};

void initBLE(){
  // Initialise the module 
  SerialDebug.print(F("Init BLE:"));
  // Create the BLE Device
  BLEDevice::init(BLE_SERVICE_NAME);
  //BLEDevice::init("WAHOO BLUESC");
  
  // Create the BLE Server
  BLEServer *pServer = BLEDevice::createServer();
  pServer->setCallbacks(new MyServerCallbacks());
  
  // Add the Fitness Machine Service definition 
  // Service ID should be 1 
  SerialDebug.println(F("Adding the Fitness Machine Service definition (UUID = 0x1826): "));
  // Create the BLE Service
  BLEService *pService = pServer->createService(BLEUUID((uint16_t)FitnessMachineService));

  // Add the Fitness Machine Rower Data characteristic 
  // Chars ID for Measurement should be 1 
    pDtCharacteristic = pService->createCharacteristic(
          BLEUUID((uint16_t)FitnessMachineRowerData),
          BLECharacteristic::PROPERTY_NOTIFY
          );
    pDtCharacteristic->addDescriptor(new BLE2902());      
    pDtCharacteristic->setCallbacks(new MyCallbacks());

    pFmfCharacteristic = pService->createCharacteristic(
          BLEUUID((uint16_t)FitnessMachineFeature),
          BLECharacteristic::PROPERTY_READ
          );
    pFmfCharacteristic->addDescriptor(new BLE2902());

    // Add the Fitness Machine Control Point characteristic 
    pCtrCharacteristic = pService->createCharacteristic(
          BLEUUID((uint16_t)FitnessMachineControlPoint),
          BLECharacteristic::PROPERTY_WRITE 
          );
    pCtrCharacteristic->addDescriptor(new BLE2902());
    pCtrCharacteristic->setCallbacks(new MyCallbacks());

    pBatCharacteristic = pService->createCharacteristic(
          BLEUUID((uint16_t)batteryLevel),
          BLECharacteristic::PROPERTY_NOTIFY
          );
    pBatCharacteristic->addDescriptor(new BLE2902());

    // Add the Fitness Machine Status characteristic 
    pStCharacteristic = pService->createCharacteristic(
          BLEUUID((uint16_t)FitnessMachineStatus),
          BLECharacteristic::PROPERTY_NOTIFY
          );
    pStCharacteristic->addDescriptor(new BLE2902());

  // Start the service
  pService->start();

 
  //-------------------------------------------------------------------------------------

  BLEService *pService2 = pServer->createService(BLEUUID((uint16_t)DEVICE_INFORMATION));
  pCharacteristic24 = pService2->createCharacteristic(
    BLEUUID((uint16_t)0x2A24),
    BLECharacteristic::PROPERTY_READ
    );
  pCharacteristic25 = pService2->createCharacteristic(
    BLEUUID((uint16_t)0x2A25),
    BLECharacteristic::PROPERTY_READ
    );
  pCharacteristic26 = pService2->createCharacteristic(
    BLEUUID((uint16_t)0x2A26),
    BLECharacteristic::PROPERTY_READ
    );    
  pCharacteristic27 = pService2->createCharacteristic(
    BLEUUID((uint16_t)0x2A27),
    BLECharacteristic::PROPERTY_READ
    );
  pCharacteristic28 = pService2->createCharacteristic(
    BLEUUID((uint16_t)0x2A28),
    BLECharacteristic::PROPERTY_READ
    );
  pCharacteristic29 = pService2->createCharacteristic(
    BLEUUID((uint16_t)0x2A29),
    BLECharacteristic::PROPERTY_READ
    );            
  pService2->start();

  pCharacteristic24->setValue("4");
  pCharacteristic25->setValue("0000");
  pCharacteristic26->setValue("0.30");
  pCharacteristic27->setValue("2.2BLE");
  pCharacteristic28->setValue("4.3");
  pCharacteristic29->setValue("Waterrower");

  char cRower[8];
  cRower[0]=0x26;
  cRower[1]=0x56;
  cRower[2]=0x00;
  cRower[3]=0x00;
  cRower[4]=0x00;
  cRower[5]=0x00;
  cRower[6]=0x00;
  cRower[7]=0x00;
  pFmfCharacteristic->setValue((uint8_t* )cRower, 8);

//--------------------------------------------------------------------------------------------------------

  // Start advertising
  SerialDebug.println(F("Adding Fitness Machine Service UUID to the advertising payload "));
  BLEAdvertising *pAdvertising = pServer->getAdvertising();
  BLEAdvertisementData oAdvertisementData;
  oAdvertisementData.addData(std::string{ 0x02, 0x01, 0x06, 0x05, 0x02, 0x26, 0x18, 0x0a, 0x18});
  //oAdvertisementData.addData(std::string{ 0x01, 0xFC});
  pAdvertising->setScanResponse(true);
  pAdvertising->setAdvertisementData(oAdvertisementData);

  //pAdvertising->addServiceUUID(BLEUUID((uint16_t)GATT_CSC_UUID));
  pAdvertising->addServiceUUID(BLEUUID((uint16_t)FitnessMachineService));
  //pAdvertising->setAppearance(833);
  //pAdvertising->setAppearance(1154); //BLE_APPEARANCE_CYCLING_SPEED_SENSOR
  BLEDevice::startAdvertising();

  bleInitFlag=true;
  SerialDebug.println();
}

void initBleData(){
  rdKpi.bpm=0;
  rdKpi.strokeCount=0;
  //rdKpi.tmpstrokeRate=0;
  rdKpi.strokeRate=0;
  rdKpi.averageStokeRate=0;
  rdKpi.totalDistance=0;
  rdKpi.tmpinstantaneousPace=0;
  rdKpi.instantaneousPace=0;
  rdKpi.averagePace=0;
  rdKpi.instantaneousPower=0;
  rdKpi.averagePower=0;
  rdKpi.resistanceLevel=0;
  rdKpi.totalEnergy=0;
  rdKpi.energyPerHour=0;
  rdKpi.energyPerMinute=0;
  rdKpi.heartRate=0;
  rdKpi.metabolicEquivalent=0;
  rdKpi.elapsedTime=0;
  rdKpi.elapsedTimeSec=0;
  rdKpi.elapsedTimeMin=0;
  rdKpi.elapsedTimeHour=0;
  rdKpi.remainingTime=0;
}

void setCxLightRowerData(){
#ifdef DEEPTRACE
  SerialDebug.printf("sendBleLightData() start");
#endif
  // This function is a subset of field to be sent in one piece
  // An alternative to the sendBleData()
  uint16_t  rowerDataFlags=0b0000001111110; //0x7E
  
  // 0000000000001 - 1   - 0x001 + More Data 0 <!> WARNINNG <!> This Bit is working the opposite way, 0 means field is present, 1 means not present
  // 0000000000010 - 2   - 0x002 + Average Stroke present
  // 0000000000100 - 4   - 0x004 + Total Distance Present
  // 0000000001000 - 8   - 0x008 + Instantaneous Pace present
  // 0000000010000 - 16  - 0x010 + Average Pace Present
  // 0000000100000 - 32  - 0x020 + Instantaneous Power present
  // 0000001000000 - 64  - 0x040 + Average Power present
  // 0000010000000 - 128 - 0x080 - Resistance Level present
  // 0000100000000 - 256 - 0x080 + Expended Energy present
  // 0001000000000 - 512 - 0x080 - Heart Rate present
  // 0010000000000 - 1024- 0x080 - Metabolic Equivalent present
  // 0100000000000 - 2048- 0x080 - Elapsed Time present
  // 1000000000000 - 4096- 0x080 - Remaining Time present

  //  C1  Stroke Rate             uint8     Position    2  + (After the Flag 2bytes)
  //  C1  Stroke Count            uint16    Position    3  +
  //  C2  Average Stroke Rate     uint8     Position    5  +
  //  C3  Total Distance          uint24    Position    6  +
  //  C4  Instantaneous Pace      uint16    Position    9  +
  //  C5  Average Pace            uint16    Position    11 +
  //  C6  Instantaneous Power     sint16    Position    13 +
  //  C7  Average Power           sint16    Position    15 +
  //  C8  Resistance Level        sint16    Position    17 -
  //  C9  Total Energy            uint16    Position    19 +
  //  C9  Energy Per Hour         uint16    Position    21 +
  //  C9  Energy Per Minute       uint8     Position    23 +
  //  C10 Heart Rate              uint8     Position    24 -
  //  C11 Metabolic Equivalent    uint8     Position    25 -
  //  C12 Elapsed Time            uint16    Position    26 -
  //  C13 Remaining Time          uint16    Position    28 -

  char cRower[17];

  cRower[0]=rowerDataFlags & 0x000000FF;
  cRower[1]=(rowerDataFlags & 0x0000FF00) >> 8;
  
  //rdKpi.strokeRate=rdKpi.tmpstrokeRate*2;
  cRower[2] = rdKpi.strokeRate & 0x000000FF;
  
  cRower[3] = rdKpi.strokeCount & 0x000000FF;
  cRower[4] = (rdKpi.strokeCount & 0x0000FF00) >> 8;
  
  cRower[5] = rdKpi.averageStokeRate & 0x000000FF;
  
  cRower[6] = rdKpi.totalDistance &  0x000000FF;
  cRower[7] = (rdKpi.totalDistance & 0x0000FF00) >> 8;
  cRower[8] = (rdKpi.totalDistance & 0x00FF0000) >> 16;
  
  if (rdKpi.tmpinstantaneousPace>0) // Avoid Divide by Zero
    rdKpi.instantaneousPace=(100000/rdKpi.tmpinstantaneousPace)/2;
  cRower[9] = rdKpi.instantaneousPace & 0x000000FF;
  cRower[10] = (rdKpi.instantaneousPace & 0x0000FF00) >> 8;
  
  cRower[11] = rdKpi.averagePace & 0x000000FF;
  cRower[12] = (rdKpi.averagePace & 0x0000FF00) >> 8;

  cRower[13] = rdKpi.instantaneousPower & 0x000000FF;
  cRower[14] = (rdKpi.instantaneousPower & 0x0000FF00) >> 8;

  cRower[15] = rdKpi.averagePower & 0x000000FF;
  cRower[16] = (rdKpi.averagePower & 0x0000FF00) >> 8;

  //gatt.setChar(fitnessMachineRowerDataId, cRower, 17);
  pDtCharacteristic->setValue((uint8_t* )cRower, 17);
  pDtCharacteristic->notify();


#ifdef DEEPTRACE
  SerialDebug.printf("sendBleLightData() end");
#endif
}

void setCxRowerData(){
  // Due the size limitation of the message in the BLE Stack of the NRF
  // the message will be split in 2 parts with the according Bitfield (read the spec :) )
  // rowerDataFlagsP1=0b0000011111110 = 0xFE
  // rowerDataFlagsP2=0b1111100000001 = 0x1F01
 
  char cRower[19]; // P1 is the biggest part whereas P2 is 13
  
  // Send the P1 part of the Message
  cRower[0]=rowerDataFlagsP1 & 0x000000FF;
  cRower[1]=(rowerDataFlagsP1 & 0x0000FF00) >> 8;
  
  //rdKpi.strokeRate=rdKpi.tmpstrokeRate*2;
  cRower[2] = rdKpi.strokeRate & 0x000000FF;
  
  cRower[3] = rdKpi.strokeCount & 0x000000FF;
  cRower[4] = (rdKpi.strokeCount & 0x0000FF00) >> 8;
  
  cRower[5] = rdKpi.averageStokeRate & 0x000000FF;
  
  cRower[6] = rdKpi.totalDistance &  0x000000FF;
  cRower[7] = (rdKpi.totalDistance & 0x0000FF00) >> 8;
  cRower[8] = (rdKpi.totalDistance & 0x00FF0000) >> 16;
  
  cRower[9] = rdKpi.instantaneousPace & 0x000000FF;
  cRower[10] = (rdKpi.instantaneousPace & 0x0000FF00) >> 8;
  
  cRower[11] = rdKpi.averagePace & 0x000000FF;
  cRower[12] = (rdKpi.averagePace & 0x0000FF00) >> 8;

  cRower[13] = rdKpi.instantaneousPower & 0x000000FF;
  cRower[14] = (rdKpi.instantaneousPower & 0x0000FF00) >> 8;

  cRower[15] = rdKpi.averagePower & 0x000000FF;
  cRower[16] = (rdKpi.averagePower & 0x0000FF00) >> 8;

  cRower[17] = rdKpi.resistanceLevel & 0x000000FF;
  cRower[18] = (rdKpi.resistanceLevel & 0x0000FF00) >> 8;

  pDtCharacteristic->setValue((uint8_t* )cRower, 19);
  pDtCharacteristic->notify();

  // Send the P2 part of the Message
  cRower[0]=rowerDataFlagsP2 & 0x000000FF;
  cRower[1]=(rowerDataFlagsP2 & 0x0000FF00) >> 8;
         
  cRower[2] = rdKpi.totalEnergy & 0x000000FF;
  cRower[3] = (rdKpi.totalEnergy & 0x0000FF00) >> 8;

  cRower[4] = rdKpi.energyPerHour & 0x000000FF;
  cRower[5] = (rdKpi.energyPerHour & 0x0000FF00) >> 8;

  cRower[6] = rdKpi.energyPerMinute & 0x000000FF;

  cRower[7] = rdKpi.bpm & 0x000000FF;

  cRower[8] = rdKpi.metabolicEquivalent& 0x000000FF;

  //rdKpi.elapsedTime=rdKpi.elapsedTimeSec+rdKpi.elapsedTimeMin*60+rdKpi.elapsedTimeHour*3600;
  cRower[9] =   rdKpi.elapsedTime & 0x000000FF;
  cRower[10] = (rdKpi.elapsedTime & 0x0000FF00) >> 8;

  cRower[11] = rdKpi.remainingTime & 0x000000FF;
  cRower[12] = (rdKpi.remainingTime & 0x0000FF00) >> 8;
  
  pDtCharacteristic->setValue((uint8_t* )cRower, 13);
  pDtCharacteristic->notify();

}

void setCxBattery(){
  #ifdef DEEPTRACE
    SerialDebug.printf("sendBleBattery() start");
  #endif
  char hexBat[2];
  int batteryLevelPercent = round(battery_RA.getAverage() * 100 / 127);
  /*
  float measuredVbat = analogRead(VBATPIN);
  measuredVbat *= 2;    // we divided by 2, so multiply back
  measuredVbat *= 3.3;  // Multiply by 3.3V, our reference voltage
  measuredVbat /= 1024; // convert to voltage

  batteryLevelPercent=((measuredVbat-2.9)/(5.15-2.90))*100;

  SerialDebug.print("Mesured Bat:");
  SerialDebug.println(batteryLevelPercent);
  */

  hexBat[0]=batteryLevelPercent & 0x000000FF;
  hexBat[1]='\0'; // just in case 

  pBatCharacteristic->setValue((uint8_t* )hexBat, 1);
  pBatCharacteristic->notify();

  #ifdef DEEPTRACE
    SerialDebug.printf("sendBleBattery() end");
  #endif
}

void row_start() {
  display.clear();
  display.setColor(WHITE);
  display.setFont(ArialMT_Plain_24);
  display.setTextAlignment(TEXT_ALIGN_CENTER);
  display.drawString(64, 10, "Waiting");
  display.drawString(64, 34, "for start");
  display.display();
  delay(100);
  while (clicks == 0) {};

  reset();
  rowing();
}

void variableParameter(){
    //lcd.setCursor(9, 0);
    switch (stage) {
    case 1:
      //lcd.print("Rot");
      data_output = clicks;
      break;
    case 2:
      //lcd.print("Rpm");
      data_output = rpm;
    break;
    case 3:
        //lcd.print("Trend ");
        if (trend == 0){
          //lcd.print("c");
        }
        if (trend == 1){
          //lcd.print("-");
        }
        if (trend == 2){
          //lcd.print("+");
        }
      data_output = 1;
    break;
    case 4:
      //lcd.print("St ");
      data_output = strokes;
    break;
    case 5:
      //lcd.print("StA");
      data_output = stm;
    break;
    case 6:
      //lcd.print("StM");
      data_output = stmra;
    break;
    default:
       //lcd.print("Sp5");
       data_output = split_time;
    break;
    }
    if(data_output >= 10) {
      if(data_output >= 100) {
      //lcd.print(" ");
      } else {
        //lcd.print("  ");
      }
    } else {
    //lcd.print("   ");
    }
    //lcd.print(data_output);
}
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
void loop() {
  row_start();
}

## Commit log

2021-03-06 Battery bar
2024-11-06 Case for Heltec Wifi 32 + toggle switch + lipo
    [Cap.stl, Case.stl]
